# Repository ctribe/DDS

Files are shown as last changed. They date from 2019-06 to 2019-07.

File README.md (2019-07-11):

# DDS
100MHz DDS Signal Source

This signal source is based on the AD9913 DDS Chip and will interface to a STM32F4 Microcontroller. Output power and frequency are set using a rotary encoder with a push button. 

Design Goals:

Pout Max: +20dBm

Dynamic Range: 50dB

SFDR: 70dBc

Frequency Range: 10kHz - 100MHz

User Interface:
LCD & Rotary Encoder

Features:

1dB incremental adjustments

Variable frequency step size

Coax output

More info coming soon.

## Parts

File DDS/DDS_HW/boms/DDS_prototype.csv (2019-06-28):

Qty | Parts | Value | Device | P/N
1 | J3 |  | 1X3_MALE_HEADER_0.1
2 | J1, J2 |  | 1X6_MALE_HEADER_0.1
1 | D2 |  | LED | QBLP595-IG
2 | R1 | 4.65k | RESISTOR0402 | RC0402FR-074K64L
1 | J4 |  | SMA_EMPCB.SMAFSTJ.B.HT | EMPCB.SMAFSTJ.B.HT
4 | C3, C7, C8, C11 | 0.1u | 0402_CAP | CC0402KRX5R7BB104?
3 | R1, R6, R7 | 100k | RESISTOR0402 | ?RC0402JR-07100KL?
2 | C9, C12 | 100p | 0402_CAP | CC0402JRNPO9BN101
4 | C4, C5, C6, C10 | 1u | 0402_CAP | CC0402KRX5R7BB105
1 | R8 | 100 | RESISTOR0402 | ?RC0402JR-07100RL?
2 | R3, R4 | 49.9 | 0402_RESISTOR | ?RC0402JR-07100KL?
2 | C1, C2 | 7pF | 0402_CAP | CC0402DRNPO9BN7R0?
1 | U1 | AD9913 | AD9913 | AD9913
1 | T1 | ADTT1-6+ | ADTT1-6+ | ADTT1-6+
2 | FB1, FB2 | BLM18KG102SN1D | 0603_FB | BLM18KG102SN1D
1 | D1 | LSM115JE3 | SCHOTTKEY | LSM115JE3
1 | U2 | S-1711A1818-I6T1U | S-1711 | S-1711A1818-I6T1U
1 | Y1 | TSX-3225 25.0000MF10P-C0 | TSX-3225 | TSX-3225 25.0000MF10P-C0
1 | N/A |  | Jumper for J3 | ?QPC02SXGN-RC?

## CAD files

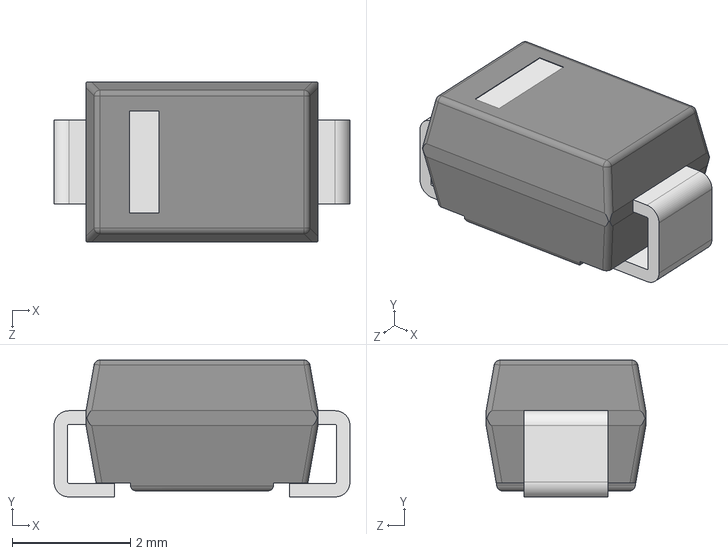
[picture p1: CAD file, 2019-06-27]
DDS/DDS_HW/models/User Library-Diode Molded Body.step
5.00 x 2.31 x 2.70 mm

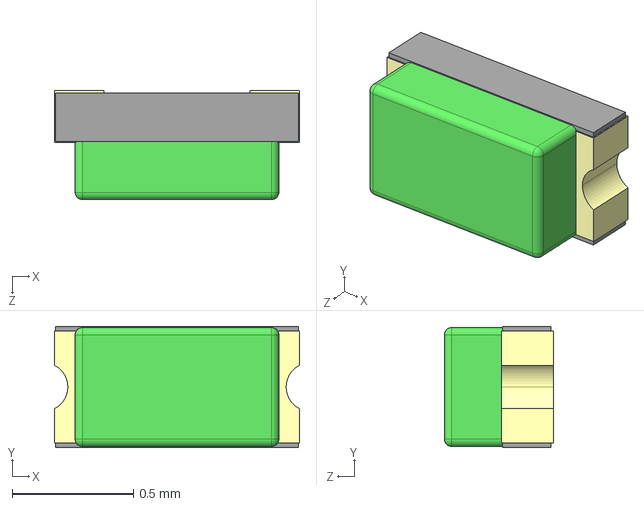
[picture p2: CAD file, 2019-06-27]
DDS/DDS_HW/models/User Library-led_0402_green.step
1.01 x 0.5 x 0.45 mm

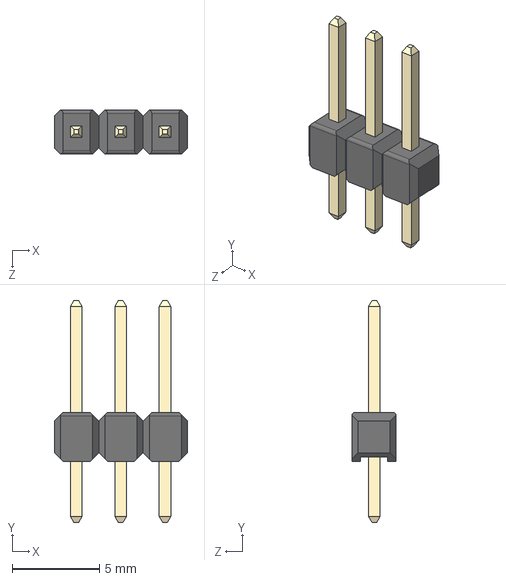
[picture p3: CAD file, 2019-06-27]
DDS/DDS_HW/models/User Library-1x3 TH Pitch 2_54mm.STEP
7.62 x 12.7 x 2.54 mm
User Library-1x3 TH Pitch 2_54mm_holder
User Library-1x3 TH Pitch 2_54mm_pin x 3

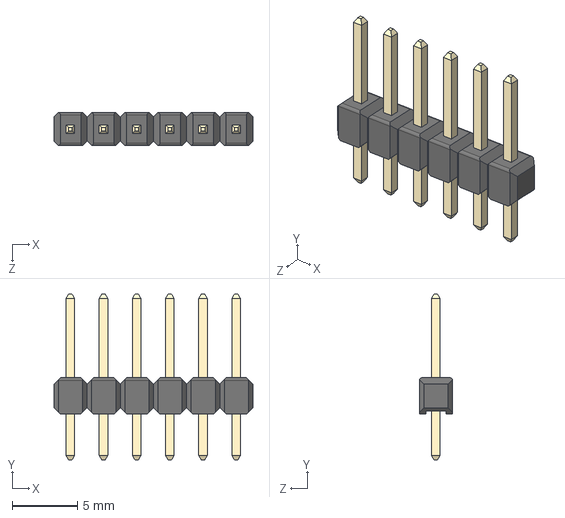
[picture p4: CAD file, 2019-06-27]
DDS/DDS_HW/models/User Library-1x6 TH Pitch 2_54mm.STEP
15.2 x 12.7 x 2.54 mm
User Library-1x6 TH Pitch 2_54mm_holder
User Library-1x6 TH Pitch 2_54mm_pin x 6

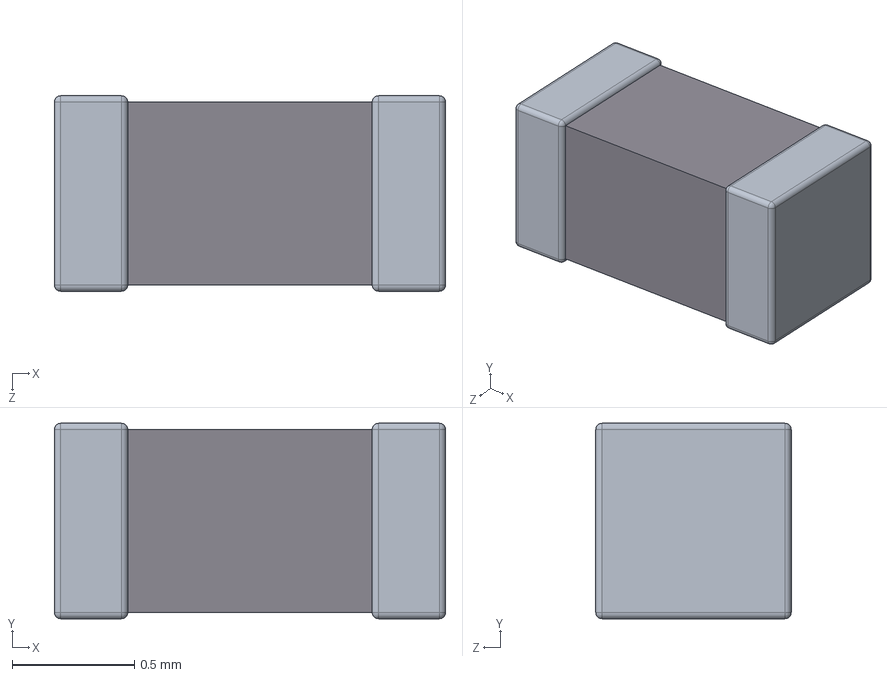
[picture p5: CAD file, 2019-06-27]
DDS/DDS_HW/models/User Library-FB_1608-1.STEP
1.60 x 0.8 x 0.8 mm
User Library-FB_1608-1_Pad001
User Library-FB_1608-1_Cut

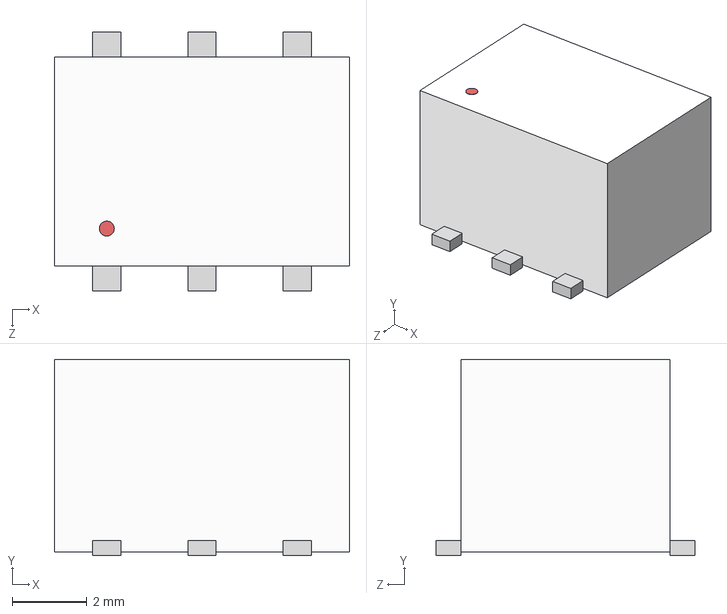
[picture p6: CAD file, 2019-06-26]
DDS/DDS_HW/models/CD637.step
7.87 x 5.24 x 6.91 mm

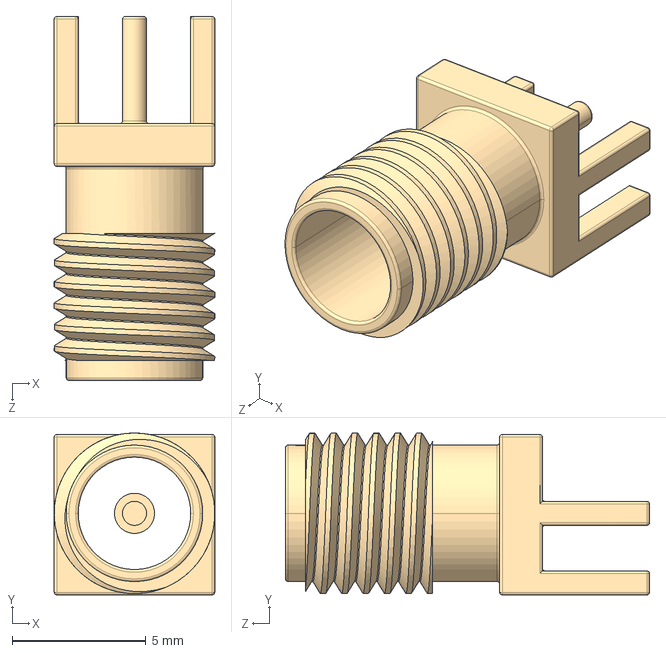
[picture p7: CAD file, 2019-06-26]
DDS/DDS_HW/models/SMA.step
6.00 x 6.05 x 13.6 mm

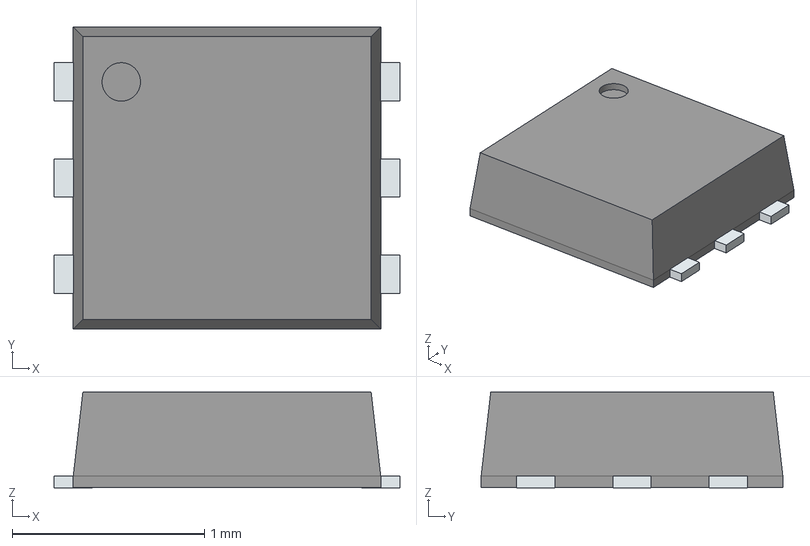
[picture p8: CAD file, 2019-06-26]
DDS/DDS_HW/models/SNT-6A.stp
1.80 x 1.57 x 0.498 mm
PinsArrayL
PinsArrayR

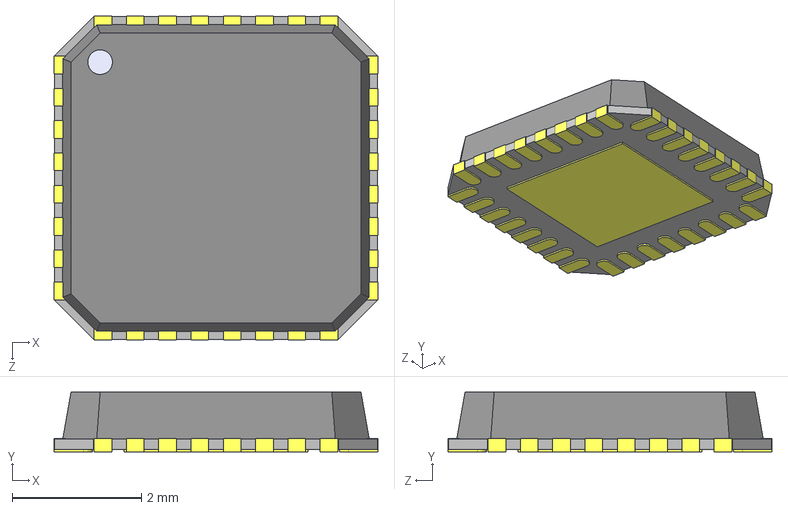
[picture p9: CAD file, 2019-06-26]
DDS/DDS_HW/models/LFCSP-32.step
5.02 x 0.925 x 5.02 mm

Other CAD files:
DDS/DDS_HW/models/User Library-led_0402_red.step

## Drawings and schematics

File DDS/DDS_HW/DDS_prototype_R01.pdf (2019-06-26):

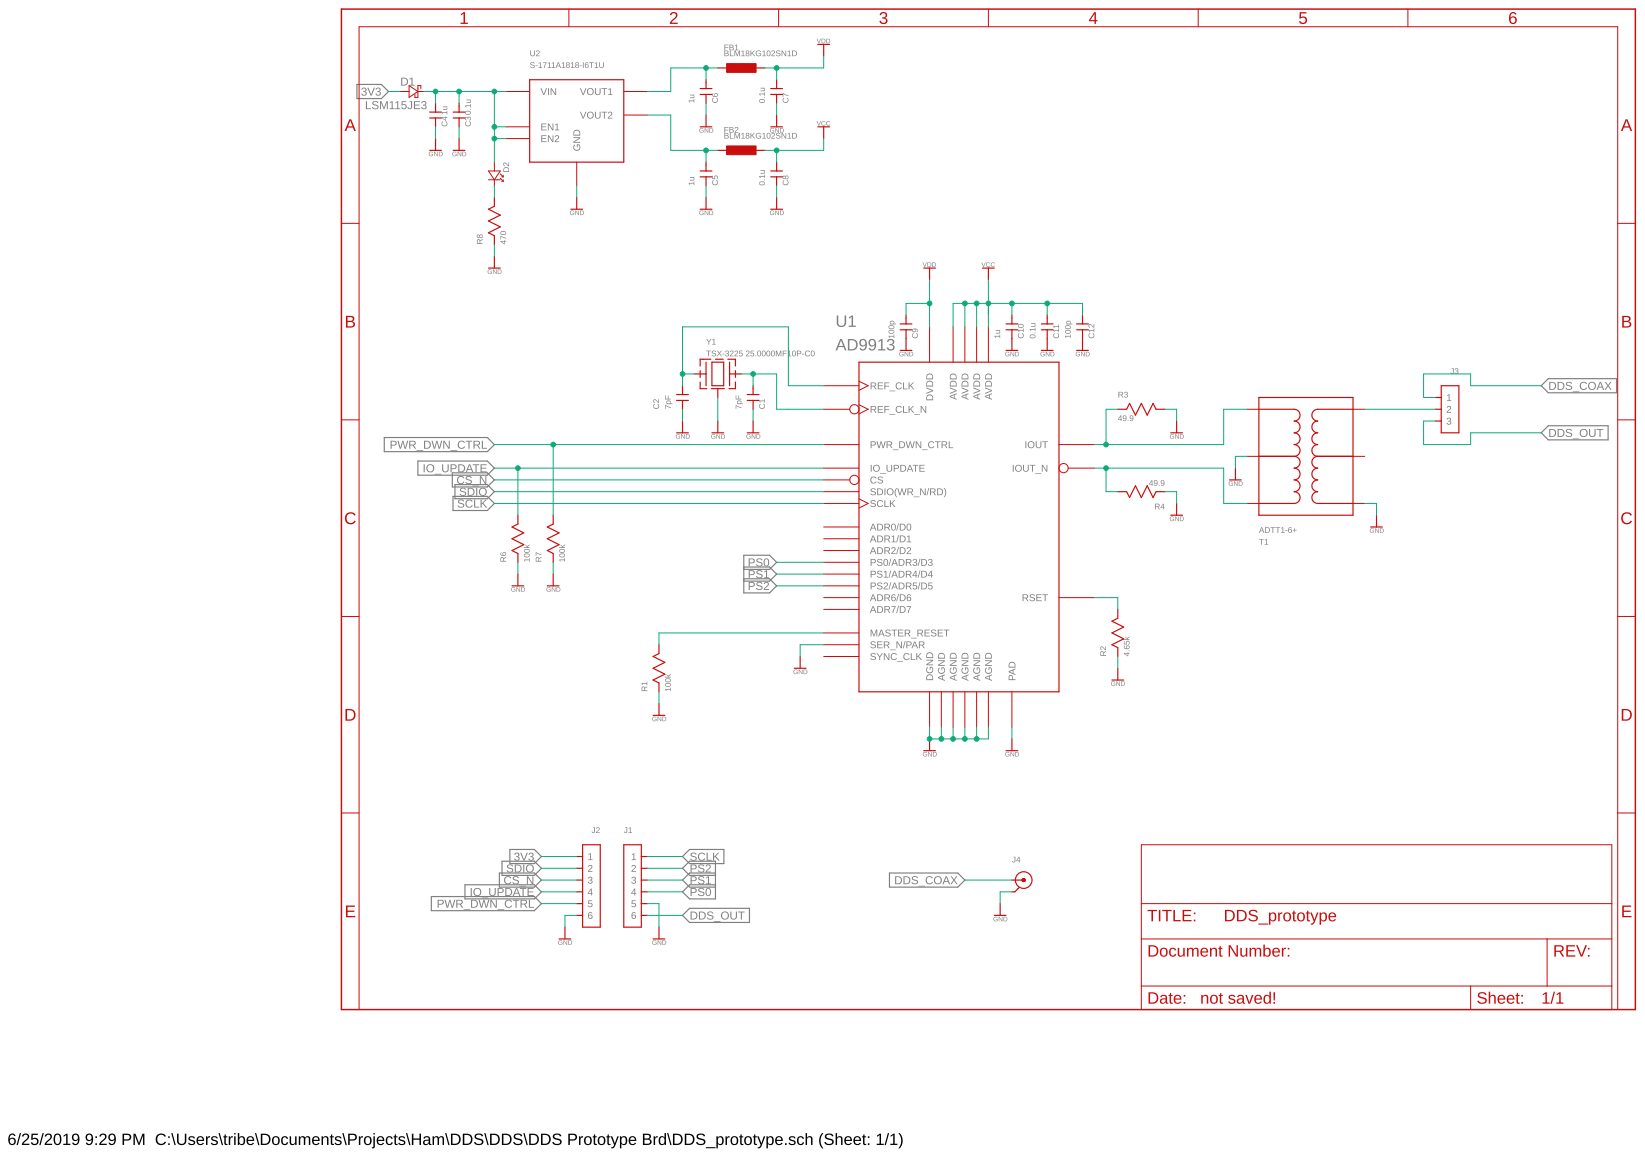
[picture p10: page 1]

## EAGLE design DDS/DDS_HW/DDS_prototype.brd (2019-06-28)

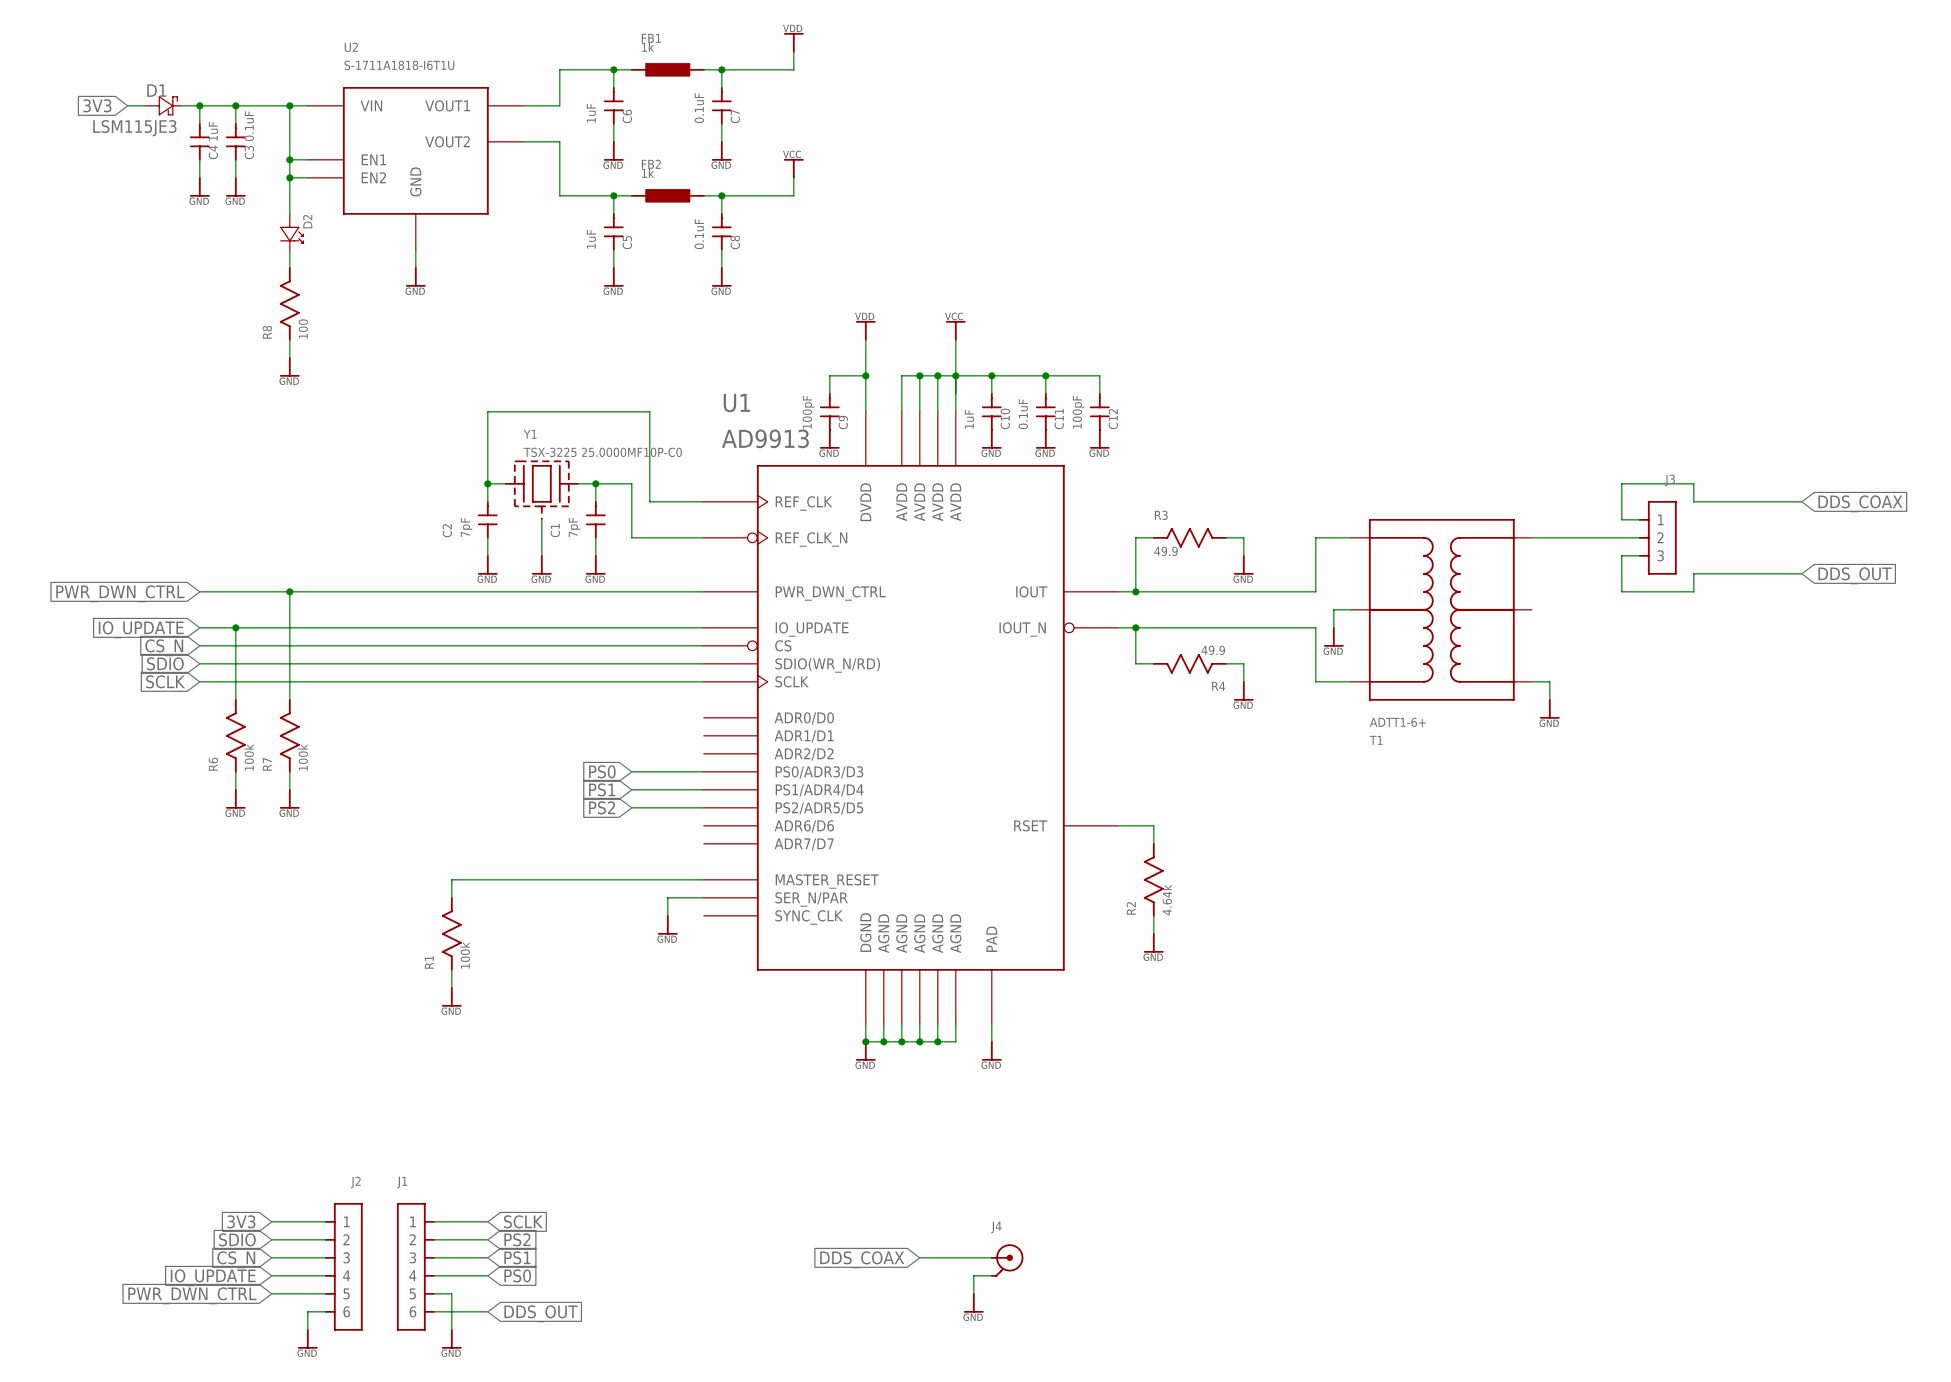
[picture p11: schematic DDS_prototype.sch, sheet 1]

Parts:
C1, C2: 7pF; 0402
C3, C7, C8, C11: 0.1uF; 0402
C4, C5, C6, C10: 1uF; 0402
C9, C12: 100pF; 0402
D1: LSM115JE3; DO-214BA
D2: QBLP595-IG; 0402_GREEN
FB1, FB2: 1k; 0603
J1, J2: 1X6_MALE_HEADER_0.1
J3: 1X3_MALE_HEADER_0.1
J4: SMA_EMPCB.SMAFSTJ.B.HT; EMPCB.SMAFSTJ.B.HT
R1, R6, R7: 100k; 0402
R2: 4.64k; 0402
R3, R4: 49.9; 0402
R8: 100; 0402
T1: ADTT1-6+; CD637
U1: AD9913; 32-LFCSP
U2: S-1711A1818-I6T1U; SNT-6A
Y1: TSX-3225 25.0000MF10P-C0; TSX-3225

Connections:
3V3: D1.A, J2.P$1 (1)
3V3_PROT: C3.2, C4.2, D1.K, D2.A, U2.P2 (VIN), U2.P4 (EN2), U2.P6 (EN1)
CS_N: J2.P$3 (3), U1.P$28 (CS)
DDS: J3.P$2 (2), T1.P$4
DDS_COAX: J3.P$1 (1), J4.P$1
DDS_OUT: J1.P$6 (6), J3.P$3 (3)
GND: C1.1, C2.1, C3.1, C4.1, C5.1, C6.1, C7.1, C8.1, C9.1, C10.1, C11.1, C12.1, J1.P$5 (5), J2.P$6 (6), J4.P$2, J4.P$3, J4.P$4, J4.P$5, R1.P$1, R2.P$1, R3.P$2, R4.P$1, R6.P$1, R7.P$1, R8.P$1, T1.P$2, T1.P$6, U1.P$5 (DGND), U1.P$10 (SER_N/PAR), U1.P$11 (AGND), U1.P$15 (AGND), U1.P$18 (AGND), U1.P$21 (AGND), U1.P$23 (AGND), U1.P$33 (PAD), U2.P5 (GND), Y1.P2, Y1.P4
IOUT: R3.P$1, T1.P$3, U1.P$19 (IOUT)
IOUT_N: R4.P$2, T1.P$1, U1.P$20 (IOUT_N)
IO_UPDATE: J2.P$4 (4), R6.P$2, U1.P$27 (IO_UPDATE)
MSTR_RST: R1.P$2, U1.P$25 (MASTER_RESET)
unnamed: D2.K, R8.P$2
unnamed: C1.2, U1.P$14 (REF_CLK_N), Y1.P3
unnamed: C2.2, U1.P$13 (REF_CLK), Y1.P1
PS0: J1.P$4 (4), U1.P$3 (PS0/ADR3/D3)
PS1: J1.P$3 (3), U1.P$2 (PS1/ADR4/D4)
PS2: J1.P$2 (2), U1.P$1 (PS2/ADR5/D5)
PWR_DWN_CTRL: J2.P$5 (5), R7.P$2, U1.P$26 (PWR_DWN_CTRL)
RSET: R2.P$2, U1.P$24 (RSET)
SCLK: J1.P$1 (1), U1.P$30 (SCLK)
SDIO: J2.P$2 (2), U1.P$29 (SDIO(WR_N/RD))
VCC: C8.2, C10.2, C11.2, C12.2, FB2.P$2, U1.P$12 (AVDD), U1.P$16 (AVDD), U1.P$17 (AVDD), U1.P$22 (AVDD)
VCC_UNFILT: C6.2, FB1.P$1, U2.P1 (VOUT1)
VDD: C7.2, C9.2, FB1.P$2, U1.P$4 (DVDD)
VDD_UNFILT: C5.2, FB2.P$1, U2.P3 (VOUT2)

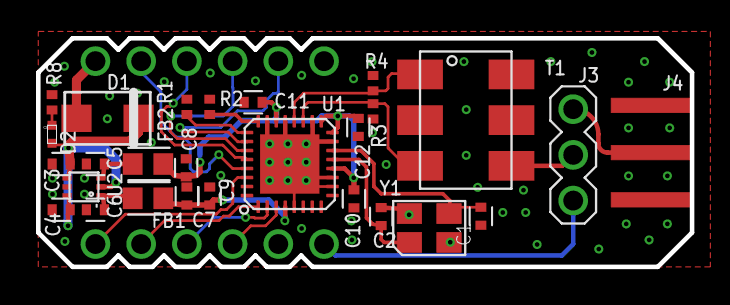
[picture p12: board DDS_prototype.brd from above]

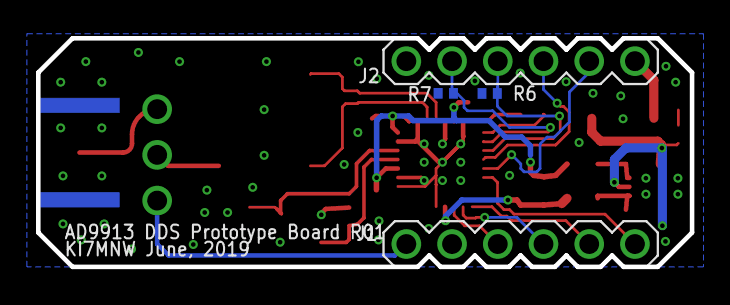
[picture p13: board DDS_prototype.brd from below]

Board: 2 copper layers, 36.3 x 12.7 mm, 31 parts (4 on the bottom side), 25 nets.

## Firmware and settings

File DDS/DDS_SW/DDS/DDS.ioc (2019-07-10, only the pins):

Mcu.UserName=STM32F415RGTx
PA5.Signal=SPI1_SCK
PA7.Signal=SPI1_MOSI

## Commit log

2019-06-25 Initial Commit of existing documents
    [DDS_prototype.brd, DDS_prototype.sch]
2019-06-25 added pull up/down res to ctrl lines
    [DDS_prototype.brd, DDS_prototype.sch]
2019-06-26 routing for pull up and pull down. not done yet.
    [DDS_prototype.brd, DDS_prototype.sch]
2019-06-26 final edits to prototype board. added bom.
    final edits to prototype board. added bom. made 3d packages.
    [CD637.step, DDS_prototype.brd, DDS_prototype.csv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]
2019-06-27 updated board, now has all 3d models, libraried are now managed libs only
    [DDS.kicad_pcb, DDS.sch, DDS_prototype.brd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]
2019-06-28 made local copy of libraries, organized dir
    [DDS.kicad_pcb, DDS.sch, DDS_prototype.brd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]
2019-07-10 removed extra copy of HW libs
    [CD637.step, DDS_prototype.brd, DDS_prototype.csv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]
